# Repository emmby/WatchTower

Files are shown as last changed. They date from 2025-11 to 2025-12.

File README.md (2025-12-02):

# The Watch Tower WWVB transmitter



There are some beautiful radio-controlled watches available these days from Citizen, Seiko, Junghans, and even Casio. These timepieces don’t need fiddling every other month, which is great if you have more than one or two and can never remember what comes after “thirty days hath September…”

In the US, these watches work by receiving a 60-bit 1-Hz signal on a 60-kHz carrier wave broadcast from Fort Collins, Colorado called [WWVB](https://en.wikipedia.org/wiki/WWVB). The broadcast is quite strong and generally covers the entire continental US, but some areas of the country can have unreliable reception. I live in the SF Bay Area in an area with high RF noise and my reception can be spotty. My watches sync often enough that it’s not an issue 363 days out of the year, but sometimes they can miss DST shifts for a day or two. The east coast is known to be even more challenging. And people who live in other countries such as Australia have generally been out of luck.

Wouldn’t it be great if anyone anywhere in the world could set up a home transmitter to broadcast the time so their watches were always in sync?

WWVB has been around awhile and there have been various other projects ([1](https://www.instructables.com/WWVB-radio-time-signal-generator-for-ATTINY45-or-A/),[2](https://github.com/anishathalye/micro-wwvb)) that have demonstrated the feasibility of making your own WWVB transmitter. But these all had very limited range. I wanted to build something that could cover my whole watch stand and be based on a more familiar toolset for the typical hobbyist, namely USB-based 32-bit microcontroller development boards, WiFi, and Arduino. My goal was to make something approachable, reliable, and attractive enough it could sit with my watch collection.

## Is this legal?

The FCC requires a license to transmit, but has an [exemption](https://www.law.cornell.edu/cfr/text/47/15.209) for 60 kHz transmitters as long as the field strength is under 40 *μ*V/m at 300 meters. You will [definitely not](https://github.com/emmby/WatchTower/issues/9) exceed this limit 💪🏼

## About WWVB

The classic WWVB transmits one bit of information per second (1Hz) and takes one minute (60 bits) to transmit a full time and date frame.

### An example

Here’s an example of one 60 second time encoding (graphic designed for "light mode"):



You can see that the minute of the time is encoded in the first 10 seconds of the window. The hour is in the next 10 seconds, the day is between seconds 22 and 33, etc.

If we wanted to indicate that the time was 30 minutes past the hour, for example, we would set bits 2 and 3 (20 and 10) to “high”. 

| **Bit** | **00** | **01** | **02** | **03** | **04** | **05** | **06** | **07** | **08** | **09** |
| --- | --- | --- | --- | --- | --- | --- | --- | --- | --- | --- |
| **Value** |  | 40 | 20 | 10 |  | 8 | 4 | 2 | 1 |  |
| *Example: 30* |  | *0* | *1* | *1* |  | *0* | *0* | *0* | *0* |  |

Similarly, the 7th hour of the day would be 0000111 for bits 12 thru 18.

### It’s a trit, not a bit.

How do we represent “high” and “low” for each 1s bit? You might think it would just be a high voltage for high and a low voltage for low, like you would use on a digital arduino pin, but that’s not how it’s done.

WWVB “bits” are actually not just 0 and 1. They’re actually "trits” because they can represent a 0, 1, or a “mark”, and this is one reason why we can’t just use a simple high/low to represent them. The mark is important to allow simple receivers to orient themselves within the signal window. Your watch knows that the last second in the window and the first in the next window are both “marks”, and so it knows to start a new window whenever it sees two marks in a row.

WWVB uses **Pulse Width Modulation** (PWM) to represent the three possible trit states. In a given 1 second bit, the width of the pulse determines whether the bit is a 0, 1, or mark.

- If power is reduced for one-fifth of a second (0.2 s), this is a data bit with value zero.
- If power is reduced for one-half of a second (0.5 s), this is a data bit with value one.
- If power is reduced for four-fifths of a second (0.8 s), this is a special non-data "mark", used for framing.

| **Low** | **Trit value** |
| --- | --- |
| 0.2s | 0 |
| 0.5s | 1 |
| 0.8s | mark |

Coming back to that original example but just focusing on the Minutes section, you can see the trits in the color encoding of the diagram. 



#07FEFF `Light blue` is high and #0001FC `Dark blue` is low. You can see second 00 is dark blue (low) for 0.8s, which means it’s a “mark”.  Second 01 is dark blue for 0.2s, so it’s a 0. Second 02 is dark blue for 0.5s so it’s a 1, and so on.

So now you know how to encode the time and date using WWVB!

### The carrier wave

There’s one more part of the signal that needs explanation. While we’re transmitting bits at a frequency of 1 bit per second (1 Hz), we’re actually doing it on top of a 60 kHz carrier wave by varying the amplitude of the carrier wave.

Like we said in the previous section, we represent a high/low/mark trit by the width of our pulse. High for 200ms is a zero, high for 500ms is a 1, high for 800ms is a mark. The way we’ll do that on our 60 kHz carrier wave is by using PWM again, but this time on the 60 kHz signal instead of on the 1 Hz signal. We’ll use a duty cycle of 50% to represent High, which means that half of our 60 kHz pulse is high and half is low. We’ll use a duty cycle of 0% to represent Low which effectively means the whole pulse is low.
 
 

 So what you'll expect to see when you're transmitting a WWVB "mark" is a 1s pulse where half of the pulse is "high" using a 60 kHz signal at 50% duty, and the other half is "low" with a 0% duty (not to scale):

 mark

 Similarly, a 0 would be a 60 kHz 50% duty cycle for 0.2s, followed by a 0% duty cycle for 0.8s. And a 1 would be the reverse.

### The layers of WWVB

In summary, a WWVB date/time is encoded using a few different layers of encoding. At the top is what we think of as a date/time and at the bottom is the 60 kHz carrier wave.

|  |
| --- |
| A date/time is encoded as a… |
| 60-bit frame, using… |
| 1s PWM trits, on top of a… |
| 60 kHz 50% duty cycle carrier wave |
| 🐢🐢🐢 all the way down |

Now that you understand how it works, let’s build the transmitter!

## Components

- An ESP32-based development board such as the AdaFruit QT Py ESP32, AdaFruit Feather ESP32 v2, Arduino Nano ESP32, Seeed Xiao ESP32C3 or similar. I used the [QT Py ESP32](https://www.adafruit.com/product/5395).
- An H-bridge amplifier circuit. You can build your own, or I used the [Adafruit DRV8833 DC/Stepper Motor Driver Breakout Board](https://www.adafruit.com/product/3297). Boards using the TB6612 would probably also work, you just need something that can handle 5V or more, a few hundred milliamps and a switching frequency of 60khz or higher.
- One or two [60khz ferrite rod antennas](https://www.canaduino.ca/product/60khz-atomic-clock-receiver-v4-wwvb-msf-jjy60/). You can pull one from an existing quartz radio-controlled movement, or I bought mine from Canaduino. If you want better reliability at distance you may consider using a second antenna. Some users have had luck with a simple 20 inch length of straight copper wire, but I found the signal to be too weak to be reliable.
- Bread board and [jumper wires](https://www.amazon.com/dp/B08YRGVYPV).
- PCB Mount Screw Terminal Block connector to connect your antenna(s), something like [this](https://www.amazon.com/dp/B09F6TC7RP). Not strictly necessary but nice to have. Use a two pin terminal if you only plan to have one antenna, or a four pin if you want two antennas.

## Optional

None of the following is necessary, but some of it might be nice to have.

- **Oscilloscope**. It can be hard to know if your circuit is doing anything without an oscilloscope. There are some micro DSOs for around $100, and some android-based table DSOs for around $200, but I like the Rigol DHO800 series as an entry-level oscilloscope if your budget can stretch to around $400. A digital multimeter or an individual LED can also be helpful in a pinch.
- **10V power supply**. If you need more power you can use an external power supply. I found the signal to be strong enough without it and preferred the convenience of a single USB power supply. If you want to go up to 13V, switch to the [TB6612](https://www.adafruit.com/product/2448)
- **3D printer** if you would like to print the tower enclosure for your circuit.
- **Permaboard** or **Perma-proto**. After you’ve prototyped your circuit you’ll want to move it to something more permanent. [Perma-proto](https://www.adafruit.com/product/571) is convenient because it exactly matches your breadboard layout. Permaboard is more configurable but less convenient. Either one can be cut to size.
- **Soldering iron**. If you’re using permaboard, you’ll need a soldering iron. I love the [Pinecil v2](https://pine64.com/product/pinecil-smart-mini-portable-soldering-iron/), it’s USB-powered, auto-sleep, nearly instant-on, open-source and temperature controlled.
- **GPS module**. The nice thing about using module development boards like the Feather, Grove, Arduino, etc. is their support for additional modules. The [AdaFruit Ultimate GPS FeatherWing](https://www.adafruit.com/product/3133) pairs well with their Feather boards and includes an accurate RTC. If you go GPS, you don’t necessarily need a microcontroller with WiFi.
- **LCD display**. This can be a nice touch and can make it easier to tell if your tower is working or not. I like the [Adafruit ESP32 TFT Feather](https://www.adafruit.com/product/5483) or similar. I made an earlier prototype with a screen that displayed the current time, but didn’t like the way the screen lit up my bedroom at night. You can also connect many external displays using the simple I2C connector on many dev boards.

## Instructions

### Simulator

Before you get started, you might be interested to see a simplified version of the software in action on the Wokwi Arduino online simulator.

The Watch Tower on Wokwi (https://wokwi.com/projects/431240334467357697)
https://wokwi.com/projects/431240334467357697

This simulator connects a virtual Arduino to a virtual logic analyser on PIN 4, and lets you download the output
of PIN 4 for offline viewing on your computer.

To use it:

- Run the simulator for a few seconds. Notice that D0 is
  flashing on the logic analyzer. The logs will also show
  the current date/time (which starts at Jan 1 1970 since
  we aren't using wifi to initialize it to another value)
- Stop the simulator. The logic analyzer will automatically
  download `wokwi-logic.vcd` to your computer.
- Open `wokwi-logic.vcd` in a viewer like [PulseView](https://sigrok.org/wiki/PulseView)

### Software

https://github.com/emmby/WatchTower

Upload the Arduino sketch to your Arduino using the Arduino IDE.

The LED will light up yellow/orange while connecting to WiFi. If you haven’t yet set your SSID, connect your phone to SSID: WWVB and follow the instructions to enter your wifi password.

Once the network is connected and the time has sync’d, the light will turn green briefly and then turn off.

**Setup()**

The Arduino setup() method does a few things.

Initialize the components we’ll be using, particularly the serial port, LEDs, WiFi, output pins, timezone, and network time sync (NTP). The network time sync will happen automatically in the background every hour. This is important because the realtime clock (RTC) on most microcontrollers are notoriously subject to drift and are rarely accurate for more than a few hours.

Start the 60 kHz carrier wave at a 50% duty cycle.

**Loop()**

Arduino then moves to the loop(), which continuously performs the following operations:

- Get the current time in UTC
- Convert it to your local timezone to determine DST
- Compute whether the 60 kHz carrier wave should be set to 50% (logical high) or 0% (logical low) for that specific moment in time. Time is always UTC, except for the DST bit which is relative to your local timezone.
- Set the PIN_ANTENNA to high or low based on that value.
- [Optional] you can flash the led for high/low PWM. This is nice for making sure things are working, but it’s grounds for divorce in the bedroom.

Do some other nice-to-haves like logging, setting LEDs and/or rebooting when there are issues.

### Verify the microcontroller alone

If you installed and ran your software and you set up the wifi connection, your board should now be outputting a signal on your output pin.

If you have an LED, you can connect the long end (anode) to your output pin and the other end to ground. If everything is working it should flash on/off about once a second.



If you have a digital oscilloscope, you should be able to see a 3V square wave with a periodicity of 16us (1 / 60,000) something like the following:



That’s the 50% duty cycle PWM carrier wave initialized during setup().

If you zoom out to say 1 second per grid square resolution, you’ll be able to see the WWVB signal clearly:



In the 10 seconds shown here, I see a 1, mark, 0, 1, 1, mark, 1, 1, 1, and 1.

Now if you modify the software to hardcode the date to Mar 6, 2008 7:30:00 am and zoom out to see a full 60 seconds, your signal should exactly match the signal in the example we started with:

```c
  buf_now_utc.tm_year = buf_now_local.tm_year = 108; // 2008 = 1900 + 108
  buf_now_utc.tm_yday = buf_now_local.tm_yday = 65;
  buf_now_utc.tm_mon = buf_now_local.tm_mon = 2;
  buf_now_utc.tm_mday = buf_now_local.tm_mday = 6;
  buf_now_utc.tm_hour = buf_now_local.tm_hour = 7;
  buf_now_utc.tm_min = buf_now_local.tm_min = 30;
```





Looks great! Everything is working as expected.

### Electronics assembly

Now that you’ve verified the microcontroller is working, it’s time to put all the components together.

The electronics consist of three basic components: the microcontroller board, the amplifier breakout board, and the antenna(s).

The connections are quite simple, you can do them on a breadboard or a proto board. I recommend starting with a breadboard, which will look identical to this perma-proto board but without the solder:



**Microcontroller board** (Adafruit ESP32 QT Py in this photo)

- Connect the 5V pin to the power plane (photo: J1).
- Connect the ground pin to the ground plane (photo: J2).
- Connect your signal pin [M0] to the input pin of your amplifier [AIN1] (photo: J4>J15).

**DRV8833 Amplifier breakout**

I decided to leave a gap between my microcontroller board and my amplifier board. This will support an optional second antenna mounted vertically, and it also makes it easier to access the STEMMA QT I2c connector on the QT Py.

- Connect the second input pin [AIN2] of your amplifier to ground (photo: J16).
- The Adafruit DRV8833 motor driver board has a sleep pin that needs to be pulled high to enable the breakout, so connect that to power 5v or 3v power, whatever is convenient. We used 5V here. (photo: J17)
- Connect ground to the ground plane. (photo: J21)
- [Optional] Connect the “motor” voltage [VM] to your 5V plane (photo: J22). This is needed if you are powering your amplifier via USB like I have here, but it should not be done if you are planning to use an external power supply on VMotor.
The antenna and amplifier circuit can contribute some noise to your 5V line. If you’re worried about it you might use an external power supply instead, but I found for these settings that the noise was negligible (although see Alternatives Considered for some lessons learned).
- Optional: connect BIN2 to ground (photo: J18). This is only needed if you want to use a second antenna.
- Optional: connect BIN1 to AIN1 (**not in photo**: I15>I19). For a second antenna.

**Antenna(s)**

- You can plug your antennas directly into your breadboard, or use a 0.1" Pitch PCB Mount Screw Terminal Block Connector connected to [AOUT1], [AOUT2], [BOUT2], and [BOUT1] (photo: C16, C17, C18, C19). If you are only using one antenna, you only need [AOUT1] and [AOUT2].

  The orientation of the antenna has a profound effect on the strength of the signal. I recommend using a second antenna at a 90 degree orientation to the first. You won't get a more powerful signal, but by having a second signal at a 90 degree orientiation you significanly increase the chance that your watches will be able to pick up a signal (see the section on antenna orientation below). The amplifier can easily handle two antennas.

  With one antenna, I was getting around 12 inches of range with the way my watches were oriented. With the second antenna, that jumped up to more than 6 feet!

  The STL tower has a hole in the center to allow space for a 60mm ferrite rod antenna mounted vertically in the gap between the microcontroller and amplifier PCBs.

### Signal Verification

You should be able to do the same LED trick as last time, only this time with the long anode on AOUT1 and the short cathode on AOUT2.

Or with your oscilloscope, you can look at the output of your microcontroller and compare it to the output of your amplifier:



Here the 3V signal on the microcontroller is blue, and you can see that the amplifier is outputting a similar wave but at 5V. If your wave doesn’t look quite like this, check that your antenna is plugged in. The antenna has an impedance that will cause the ringing that you see in the waveform, that’s expected and okay.

The final test is to verify it works with a real watch!



### Assembling the enclosure

The enclosure is designed for a 51mm x 63mm perma-proto, which is the size of a half size perma-proto with the excess trimmed. You can trim a proto board by scoring along a straightedge with a utility knife and then bending the board at the score, either by pressing it down on a hard surface at an angle or using a vise grip. Or feel free to modify the Autodesk Fusion file to the size of your own board.



Here I also made a quick and dirty “mount” for the antenna by twisting a couple of loops of wire and soldering them to the perma proto. Hot glue also works great.

Print the enclosure using a 3D printer. I used standard PLA, standard 0.4mm nozzle, and pretty much default slicer settings with no supports.

* STL: [The Watch Tower.stl](enclosure/The%20Watch%20Tower%20v18.stl)
* Autodesk Fusion: [The Watch Tower.f3d](enclosure/The%20Watch%20Tower%20v18.f3d)



Insert the circuit board into the base. Orient the second antenna between the two PCBs and fit it into the hole in the tower. Then press the lid for a snap fit.

## Enjoy!

Plug into USB and you’re done! Your watches should now sync automatically every night.



## Signal strength

### How does distance affect signal strength?

You probably expect the signal to decrease as you get further away from the tower, but you might be surprised by how quickly the signal disappears.

The "inverse square law" tells us that RF signal strength decreases with the square of the distance. We can measure our signal strength using our oscilloscope, another antenna, and a ruler.

signal strength at 1 inch setup

At one inch, our signal strength looks pretty solid! You can see that our 5V antenna square wave (yellow) is inducing a 16V sinusoidal wave in our receiving antenna. It's a little counter-intuitive that the receiving amplitude would be larger than the sending amplitude, but RF physics is beyond the scope of this README. Which is another way of saying 🤷.

signal strength at 1 inch

Here are my readings as I move the receiver antenna further out. As expected, the amplitude decreases by roughly 4X as the distance doubles. 

| Distance | Amplitude |
|----|---|
| 1" | 24.2V |
| 2" | 6.7V |
| 4" | 1.2V |
| 8" | 301mV |
| 16" | 93mV |
| 32" | 28mV |

When you zoom out, the one second pulses are still clearly distinguishable to the human eye, but it gets harder and harder as you get further away.



This is all fine and good, but seeing a wave on an oscilloscope doesn't necessarily mean the watch can pick it up. We'll get into that shortly.

### How does orientation affect signal strength?

Quite a lot!

Turning the receiver antenna 90 degrees drops the signal by 75%!

rotation

Most watches receive their strongest signal through the watch face. For the best reception you should point your watch toward the tower (or toward Colorado). This may make more of a difference than a few inches of distance.

This doesn't matter for watches on the stand where the signal is strong, but it can make a difference for watches that are further away.

This is why I recommend two antennas at right angles from each other.

### Does the enclosure affect signal strength?

Plastic enclosures have a negligible effect on signal strength. The Watch Tower enclosure printed using generic PLA has maybe 5% or less of an impact on signal strength. Again, a few degrees of orientation will have a larger effect than an enclosure.

|||
|-|-|
|No enclosure | 1.02V |
|Base | 952mV |
|Fully enclosed | 987mV |

### How far away can my watch pick up the signal?

Watches vary in terms of their antenna design, their enclosures, antenna orientation, signal-to-noise filtering, etc.

I tested with a Junghans Max Bill Mega Solar 59/2021.02 (Seiko movement) and a Casio Lineage LIW-M700D (Casio movement). In practice, the orientation of your watch will probably have orders of magnitude more influence on your reception than the model of your watch.

Using the SINGLE antenna, I made five attempts with each watch at a distance of 9" with the antenna and the watch both flat on the surface. To minimize interference from Fort Collins, I placed everything inside a poor man's faraday cage (a stainless steel stock pot with a tight lid, which Gemini tells me is reasonably effective at blocking 60 kHz signals). For each attempt, I gave the watch 5 minutes to try to set the time before I lifted the lid. 

clock in a pot

| Model ||||||
|---|-----|-|-|-|-|
| Casio | Yes | No | Yes | Yes | Yes |
| Junghans| Yes | Yes | Yes | Yes | Yes |

Outcome: ~90% success at 9" (single antenna)

In practice, I've found that watches on the Watch Tower will reliably sync every time, and most watches on my nearby watch stand will also sync most of the time using a single antenna. Adding the second antenna increases reliability to basically 100%.

## Alternatives considered

- I wanted to avoid using a separate amplifier breakout board so I tried the Adafruit RP2040 scorpio. It can do 60khz PWM at 5V natively, but it was only able to drive 12mA per channel which wasn’t enough to saturate my ferrite antenna so the square wave collapsed.
- I looked at the **Adafruit 8-Channel PWM or Servo FeatherWing** because I wanted to take advantage of module stacking, but it can only do 10mA per channel and 1.6khz.
- I looked at Trinket and Itsybitsy ATmega based boards, but they can’t drive much current and they’re not modular with anything and they have no wifi so there’s little advantage over the QT Py.
- I considered driving the DRV8833 with an external power supply. This would have given me higher voltage and likely a stronger signal. But I wanted the convenience of a single usb power supply, and the signal strength was sufficient for my needs.
- ⚠️ **WARNING**: I tried the linking both the A and B H-bridges of the  DRV8833 in parallel, and I also upped the duty cycle to 80%. Totally blew out my microcontroller, presumably with a flyback voltage due to the high inductance antenna. I’m not sure if it was the parallel or the 80% or the combination of the two, it would be worth experimenting further but I haven’t yet.

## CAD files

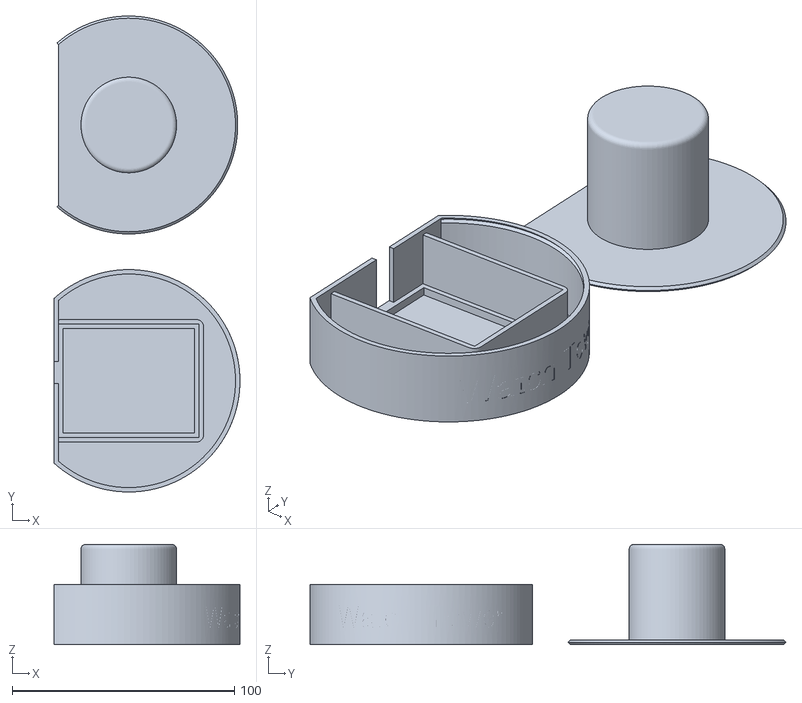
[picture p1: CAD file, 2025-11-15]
enclosure/The Watch Tower.stl
83.6 x 214.0 x 45.0

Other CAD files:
enclosure/The Watch Tower.f3d

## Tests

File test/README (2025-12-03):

This directory is intended for PlatformIO Test Runner and project tests.

Unit Testing is a software testing method by which individual units of
source code, sets of one or more MCU program modules together with associated
control data, usage procedures, and operating procedures, are tested to
determine whether they are fit for use. Unit testing finds problems early
in the development cycle.

More information about PlatformIO Unit Testing:
- https://docs.platformio.org/en/latest/advanced/unit-testing/index.html

These test can be run using the PlatformIO Test Runner.
    cmd+shift+p PlatformIO: Test in VS Code
or
    pio test -e native

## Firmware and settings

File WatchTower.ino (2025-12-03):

// INSTRUCTIONS
// - Add the following dependencies to your Arduino libraries:
//     - Adafruit NeoPixel ~1.15.2
//     - ESPUI ~2.2.4
//     - ESP32Async / ESP Async WebServer ~3.9.0
//     - ESP32Async / Async TCP ~3.4.9
//     - WiFiManager ~2.0.17
//     - ArduinoMDNS ~1.0.0
// - set the PIN_ANTENNA to desired output pin
// - set the timezone as desired
// - build and run the code on your device
// - connect your phone to "WatchTower" to set the wifi config for the device
// - connect to http://watchtower.local to view current status

// Designed for the following, but should be easily
// transferable to other components:
// - Adafruit Qt Py ESP32 Pico: https://www.adafruit.com/product/5395
// - Adafruit DRV8833 breakout: https://www.adafruit.com/product/3297
// Also tested on
// - Adafruit ESP32 Feather v2
// - Arduino Nano ESP32 (via wokwi)

#include <WiFiManager.h>
#include <Adafruit_NeoPixel.h>
#include <SPI.h>
#include <ESPUI.h>
#include <WiFiUdp.h>
#include <ArduinoMDNS.h>
#include <time.h>
#include <esp_sntp.h>
#include "customJS.h"

// Flip to false to disable the built-in web ui.
// You might want to do this to avoid leaving unnecessary open ports on your network.
const bool ENABLE_WEB_UI = true;

// Set this to the pin your antenna is connected on
const int PIN_ANTENNA = 13;

// Set to your timezone.
// This is needed for computing DST if applicable
// https://gist.github.com/alwynallan/24d96091655391107939
const char *timezone = "PST8PDT,M3.2.0,M11.1.0"; // America/Los_Angeles


enum WWVB_T {
  ZERO = 0,
  ONE = 1,
  MARK = 2,
};

const int KHZ_60 = 60000;
const char* const ntpServer = "pool.ntp.org";

// Configure the optional onboard neopixel
#ifdef PIN_NEOPIXEL
Adafruit_NeoPixel* const pixel = new Adafruit_NeoPixel(1, PIN_NEOPIXEL, NEO_GRB + NEO_KHZ800);
#else
Adafruit_NeoPixel* const pixel = NULL;
#endif

const uint8_t LED_BRIGHTNESS = 10; // very dim, 0-255
const uint32_t COLOR_READY = pixel ? pixel->Color(0, 60, 0) : 0; // green https://share.google/4WKm4XDkH9tfm3ESC
const uint32_t COLOR_LOADING = pixel ? pixel->Color(60, 32, 0) : 0; // orange https://share.google/7tT5GPxskZi8t8qmx
const uint32_t COLOR_ERROR = pixel ? pixel->Color(150, 0, 0) : 0; // red https://share.google/nx2jWYSoGtl0opkzL
const uint32_t COLOR_TRANSMIT = pixel ? pixel->Color(32, 0, 0) : 0; // dim red https://share.google/wYFYM3t1kDeOJfr1U

WiFiManager wifiManager;
WiFiUDP udp;
MDNS mdns(udp);
bool logicValue = 0; // TODO rename
struct timeval lastSync;
WWVB_T broadcast[60];

// ESPUI Interface IDs
uint16_t ui_time;
uint16_t ui_date;
uint16_t ui_timezone;
uint16_t ui_broadcast;
uint16_t ui_uptime;
uint16_t ui_last_sync;

// A callback that tracks when we last sync'ed the
// time with the ntp server
void time_sync_notification_cb(struct timeval *tv) {
  lastSync = *tv;
}

// A callback that is called when the device
// starts up an access point for wifi configuration.
// This is called when the device cannot connect to wifi.
void accesspointCallback(WiFiManager*) {
  Serial.println("Connect to SSID: WatchTower with another device to set wifi configuration.");
}

// Convert a logical bit into a PWM pulse width.
// Returns 50% duty cycle (128) for high, 0% for low
static inline short dutyCycle(bool logicValue) {
  return logicValue ? (256*0.5) : 0; // 128 == 50% duty cycle
}

static inline int is_leap_year(int year) {
    return (year % 4 == 0) && (year % 100 != 0 || year % 400 == 0);
}

void clearBroadcastValues() {
    for(int i=0; i<sizeof(broadcast)/sizeof(broadcast[0]); ++i) {
        broadcast[i] = (WWVB_T)-1; // -1 isn't legal but that's okay, we just need an invalid value
    }
}

void setup() {
  Serial.begin(115200);
  delay(1000);

  pinMode(PIN_ANTENNA, OUTPUT);
  if( pixel ) {
    pixel->begin();
    pixel->setBrightness(LED_BRIGHTNESS); // very dim
    pixel->setPixelColor(0, COLOR_LOADING );
    pixel->show();
  }

  // E (14621) rmt: rmt_new_tx_channel(269): not able to power down in light sleep
  digitalWrite(PIN_ANTENNA, 0);

  // https://github.com/tzapu/WiFiManager/issues/1426
  WiFi.setScanMethod(WIFI_ALL_CHANNEL_SCAN);

  // Connect to WiFi using // https://github.com/tzapu/WiFiManager 
  // If no wifi, start up an SSID called "WatchTower" so
  // the user can configure wifi using their phone.
  wifiManager.setAPCallback(accesspointCallback);
  wifiManager.autoConnect("WatchTower");

  clearBroadcastValues();

  // --- ESPUI SETUP ---
  ESPUI.setVerbosity(Verbosity::Quiet);
  
  // Create Labels
  ui_broadcast = ESPUI.label("Broadcast Waveform", ControlColor::Sunflower, "");
  ui_time = ESPUI.label("Current Time", ControlColor::Turquoise, "Loading...");
  ui_date = ESPUI.label("Date", ControlColor::Emerald, "Loading...");
  ui_timezone = ESPUI.label("Timezone", ControlColor::Peterriver, timezone);
  ui_uptime = ESPUI.label("System Uptime", ControlColor::Carrot, "0s");
  ui_last_sync = ESPUI.label("Last NTP Sync", ControlColor::Alizarin, "Pending...");

  ESPUI.setPanelWide(ui_broadcast, true);
  ESPUI.setElementStyle(ui_broadcast, "font-family: monospace");
  ESPUI.setCustomJS(customJS);

  // You may disable the internal webserver by commenting out this line
  if( ENABLE_WEB_UI ) {
    mdns.begin(WiFi.localIP(), "watchtower");
    Serial.println("Connect to http://watchtower.local for the console");
    ESPUI.begin("WatchTower");
  }
  
  // --- TIME SYNC ---

  // Connect to network time server
  // By default, it will resync every few hours
  sntp_set_time_sync_notification_cb(time_sync_notification_cb);
  configTzTime(timezone, ntpServer);
  
  struct tm timeinfo;
  if(!getLocalTime(&timeinfo)){
    Serial.println("Failed to obtain time");
    if( pixel ) {
        pixel->setPixelColor(0, COLOR_ERROR );
        pixel->show();
    }
    delay(3000);
    ESP.restart();
  }
  Serial.println("Got the time from NTP");

  // Start the 60khz carrier signal using 8-bit (0-255) resolution
  ledcAttach(PIN_ANTENNA, KHZ_60, 8);

  // green means go
  if( pixel ) {
    pixel->setPixelColor(0, COLOR_READY );
    pixel->show();
    delay(3000);
    pixel->clear();  
    pixel->show();
  }
}

void loop() {
  mdns.run();

  struct timeval now; // current time in seconds / millis
  struct tm buf_now_utc; // current time in UTC
  struct tm buf_now_local; // current time in localtime
  struct tm buf_today_start, buf_tomorrow_start; // start of today and tomrrow in localtime
  static int prev_second_display = -1; // for tracking UI updates

  gettimeofday(&now,NULL);
  localtime_r(&now.tv_sec, &buf_now_local);
  gmtime_r(&now.tv_sec, &buf_now_utc); 

  // compute start of today for dst
  struct timeval today_start = now;
  today_start.tv_usec = 0;
  today_start.tv_sec = (today_start.tv_sec / 86400) * 86400; // This is not exact but close enough
  localtime_r(&today_start.tv_sec, &buf_today_start);

  // compute start of tomorrow for dst
  struct timeval tomorrow_start = now;
  tomorrow_start.tv_usec = 0;
  tomorrow_start.tv_sec = ((tomorrow_start.tv_sec / 86400) + 1) * 86400; // again, close enough
  localtime_r(&tomorrow_start.tv_sec, &buf_tomorrow_start);

  const bool prevLogicValue = logicValue;

  logicValue = wwvbLogicSignal(
    buf_now_utc.tm_hour,
    buf_now_utc.tm_min,
    buf_now_utc.tm_sec, 
    now.tv_usec/1000,
    buf_now_utc.tm_yday+1,
    buf_now_utc.tm_year+1900,
    buf_today_start.tm_isdst,
    buf_tomorrow_start.tm_isdst
    );

  // --- UI UPDATE LOGIC ---
  if( logicValue != prevLogicValue ) {
    ledcWrite(PIN_ANTENNA, dutyCycle(logicValue));  // Update the duty cycle of the PWM

    // light up the pixel if desired
    if( pixel ) {
      if( logicValue == 1 ) {
        pixel->setPixelColor(0, COLOR_TRANSMIT ); // don't call show yet, the color may change
      } else {
        pixel->clear();
      }
    }

    // do any logging after we set the bit to not slow anything down,
    // serial port I/O is slow!
    char timeStringBuff[100]; // Buffer to hold the formatted time string
    char timeStringBuff2[100];
    char timeStringBuff3[20];
    strftime(timeStringBuff, sizeof(timeStringBuff), "%A, %B %d %Y %H:%M:%S", &buf_now_local); // time
    strftime(timeStringBuff3, sizeof(timeStringBuff3), "%z %Z", &buf_now_local); // timezone
    sprintf(timeStringBuff2,"%s.%03d%s", timeStringBuff, now.tv_usec/1000, timeStringBuff3 ); // time+millis+tz

    char lastSyncStringBuff[100]; // Buffer to hold the formatted time string
    struct tm buf_lastSync;
    localtime_r(&lastSync.tv_sec, &buf_lastSync);
    strftime(lastSyncStringBuff, sizeof(lastSyncStringBuff), "%b %d %H:%M", &buf_lastSync);
    Serial.printf("%s [last sync %s]: %s\n",timeStringBuff2, lastSyncStringBuff, logicValue ? "1" : "0");

    static int prevSecond = -1;
    if( prevSecond != buf_now_utc.tm_sec ) {
        prevSecond = buf_now_utc.tm_sec;

        // --- UPDATE THE WEB UI ---

        // Time
        char buf[62];
        strftime(buf, sizeof(buf), "%H:%M:%S%z %Z", &buf_now_local);
        ESPUI.print(ui_time, buf);

        // Date
        strftime(buf, sizeof(buf), "%A, %B %d %Y", &buf_now_local);
        ESPUI.print(ui_date, buf);

        // Broadcast window
        for( int i=0; i<60; ++i ) { // TODO leap seconds
        switch(broadcast[i]) {
            case WWVB_T::MARK:
                buf[i] = 'M';
                break;
            case WWVB_T::ZERO:
                buf[i] = '0';
                break;
            case WWVB_T::ONE:
                buf[i] = '1';
                break;
            default:
                buf[i] = ' ';
                break;
        }
        }
        ESPUI.print(ui_broadcast, buf);


        // Uptime
        long uptime = millis() / 1000;
        int up_d = uptime / 86400;
        int up_h = (uptime % 86400) / 3600;
        int up_m = (uptime % 3600) / 60;
        int up_s = uptime % 60;
        snprintf(buf, sizeof(buf), "%03dd %02dh %02dm %02ds", up_d, up_h, up_m, up_s);
        ESPUI.print(ui_uptime, buf);

        // Last Sync
        strftime(buf, sizeof(buf), "%b %d %H:%M", &buf_lastSync);
        ESPUI.print(ui_last_sync, buf);
    }

    // Check for stale sync (24 hours)
    if( now.tv_sec - lastSync.tv_sec > 60 * 60 * 24 ) {
      Serial.println("Last sync more than 24 hours ago, rebooting.");
      if( pixel ) {
        pixel->setPixelColor(0, COLOR_ERROR );
        delay(3000);
      }
      ESP.restart();
    }

    if( pixel ) {
        pixel->show();
    }
  }  
}


// Returns a logical high or low to indicate whether the
// PWM signal should be high or low based on the current time
// https://www.nist.gov/pml/time-and-frequency-division/time-distribution/radio-station-wwvb/wwvb-time-code-format
bool wwvbLogicSignal(
    int hour,                // 0 - 23
    int minute,              // 0 - 59
    int second,              // 0 - 59 (leap 60)
    int millis,
    int yday,                // days since January 1 eg. Jan 1 is 0
    int year,                // year since 0, eg. 2025
    int today_start_isdst,   // was this morning DST?
    int tomorrow_start_isdst // is tomorrow morning DST?
) {
    int leap = is_leap_year(year);
    
    WWVB_T bit;
    switch (second) {
        case 0: // mark
            bit = WWVB_T::MARK;
            break;
        case 1: // minute 40
            bit = (WWVB_T)(((minute / 10) >> 2) & 1);
            break;
        case 2: // minute 20
            bit = (WWVB_T)(((minute / 10) >> 1) & 1);
            break;
        case 3: // minute 10
            bit = (WWVB_T)(((minute / 10) >> 0) & 1);
            break;
        case 4: // blank
            bit = WWVB_T::ZERO;
            break;
        case 5: // minute 8
            bit = (WWVB_T)(((minute % 10) >> 3) & 1);
            break;
        case 6: // minute 4
            bit = (WWVB_T)(((minute % 10) >> 2) & 1);
            break;
        case 7: // minute 2
            bit = (WWVB_T)(((minute % 10) >> 1) & 1);
            break;
        case 8: // minute 1
            bit = (WWVB_T)(((minute % 10) >> 0) & 1);
            break;
        case 9: // mark
            bit = WWVB_T::MARK;
            break;
        case 10: // blank
            bit = WWVB_T::ZERO;
            break;
        case 11: // blank
            bit = WWVB_T::ZERO;
            break;
        case 12: // hour 20
            bit = (WWVB_T)(((hour / 10) >> 1) & 1);
            break;
        case 13: // hour 10
            bit = (WWVB_T)(((hour / 10) >> 0) & 1);
            break;
        case 14: // blank
            bit = WWVB_T::ZERO;
            break;
        case 15: // hour 8
            bit = (WWVB_T)(((hour % 10) >> 3) & 1);
            break;
        case 16: // hour 4
            bit = (WWVB_T)(((hour % 10) >> 2) & 1);
            break;
        case 17: // hour 2
            bit = (WWVB_T)(((hour % 10) >> 1) & 1);
            break;
        case 18: // hour 1
            bit = (WWVB_T)(((hour % 10) >> 0) & 1);
            break;
        case 19: // mark
            bit = WWVB_T::MARK;
            break;
        case 20: // blank
            bit = WWVB_T::ZERO;
            break;
        case 21: // blank
            bit = WWVB_T::ZERO;
            break;
        case 22: // yday of year 200
            bit = (WWVB_T)(((yday / 100) >> 1) & 1);
            break;
        case 23: // yday of year 100
            bit = (WWVB_T)(((yday / 100) >> 0) & 1);
            break;
        case 24: // blank
            bit = WWVB_T::ZERO;
            break;
        case 25: // yday of year 80
            bit = (WWVB_T)((((yday / 10) % 10) >> 3) & 1);
            break;
        case 26: // yday of year 40
            bit = (WWVB_T)((((yday / 10) % 10) >> 2) & 1);
            break;
        case 27: // yday of year 20
            bit = (WWVB_T)((((yday / 10) % 10) >> 1) & 1);
            break;
        case 28: // yday of year 10
            bit = (WWVB_T)((((yday / 10) % 10) >> 0) & 1);
            break;
        case 29: // mark
            bit = WWVB_T::MARK;
            break;
        case 30: // yday of year 8
            bit = (WWVB_T)(((yday % 10) >> 3) & 1);
            break;
        case 31: // yday of year 4
            bit = (WWVB_T)(((yday % 10) >> 2) & 1);
            break;
        case 32: // yday of year 2
            bit = (WWVB_T)(((yday % 10) >> 1) & 1);
            break;
        case 33: // yday of year 1
            bit = (WWVB_T)(((yday % 10) >> 0) & 1);
            break;
        case 34: // blank
            bit = WWVB_T::ZERO;
            break;
        case 35: // blank
            bit = WWVB_T::ZERO;
            break;
        case 36: // UTI sign +
            bit = WWVB_T::ONE;
            break;
        case 37: // UTI sign -
            bit = WWVB_T::ZERO;
            break;
        case 38: // UTI sign +
            bit = WWVB_T::ONE;
            break;
        case 39: // mark
            bit = WWVB_T::MARK;
            break;
        case 40: // UTI correction 0.8
            bit = WWVB_T::ZERO;
            break;
        case 41: // UTI correction 0.4
            bit = WWVB_T::ZERO;
            break;
        case 42: // UTI correction 0.2
            bit = WWVB_T::ZERO;
            break;
        case 43: // UTI correction 0.1
            bit = WWVB_T::ZERO;
            break;
        case 44: // blank
            bit = WWVB_T::ZERO;
            break;
        case 45: // year 80
            bit = (WWVB_T)((((year / 10) % 10) >> 3) & 1);
            break;
        case 46: // year 40
            bit = (WWVB_T)((((year / 10) % 10) >> 2) & 1);
            break;
        case 47: // year 20
            bit = (WWVB_T)((((year / 10) % 10) >> 1) & 1);
            break;
        case 48: // year 10
            bit = (WWVB_T)((((year / 10) % 10) >> 0) & 1);
            break;
        case 49: // mark
            bit = WWVB_T::MARK;
            break;
        case 50: // year 8
            bit = (WWVB_T)(((year % 10) >> 3) & 1);
            break;
        case 51: // year 4
            bit = (WWVB_T)(((year % 10) >> 2) & 1);
            break;
        case 52: // year 2
            bit = (WWVB_T)(((year % 10) >> 1) & 1);
            break;
        case 53: // year 1
            bit = (WWVB_T)(((year % 10) >> 0) & 1);
            break;
        case 54: // blank
            bit = WWVB_T::ZERO;
            break;
        case 55: // leap year
            bit = leap ? WWVB_T::ONE : WWVB_T::ZERO;
            break;
        case 56: // leap second
            bit = WWVB_T::ZERO;
            break;
        case 57: // dst bit 1
            bit = today_start_isdst ? WWVB_T::ONE : WWVB_T::ZERO;
            break;
        case 58: // dst bit 2
            bit = tomorrow_start_isdst ? WWVB_T::ONE : WWVB_T::ZERO;
            break;
        case 59: // mark
            bit = WWVB_T::MARK;
            break;
    }

    if(second == 0) {
        clearBroadcastValues();
    }
    broadcast[second] = bit;

    // Convert a wwvb zero, one, or mark to the appropriate pulse width
    // zero: low 200ms, high 800ms
    // one: low 500ms, high 500ms
    // mark low 800ms, high 200ms
    if (bit == WWVB_T::ZERO) {
      return millis >= 200;
    } else if (bit == WWVB_T::ONE) {
      return millis >= 500;
    } else {
      return millis >= 800;
    }
}

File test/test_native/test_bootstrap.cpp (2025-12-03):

#include <Arduino.h>
#include <unity.h>
#include <string>
#include <vector>
#include <sys/time.h>
#include <cstdarg>

// Mocks
#include "WiFiManager.h"
#include "Adafruit_NeoPixel.h"
#include "ESPUI.h"
#include "WiFiUdp.h"
#include "ArduinoMDNS.h"
#include "esp_sntp.h"
#include "WiFi.h"
#include "Esp.h"
#include "SPI.h"

// Globals for mocks
WiFiClass WiFi;
ESPUIClass ESPUI;
EspClass ESP;
SPIClass SPI;

// Core functions
void delay(unsigned long ms) {}
unsigned long millis() { return 0; }
void pinMode(uint8_t pin, uint8_t mode) {}
void digitalWrite(uint8_t pin, uint8_t val) {}

// Mock gettimeofday
struct timeval mock_tv = {0, 0};
int mock_gettimeofday(struct timeval *tv, void *tz) {
    if (tv) *tv = mock_tv;
    return 0;
}
#define gettimeofday mock_gettimeofday

// Mock Serial to support printf
class SerialMock {
public:
    std::string output;
    void begin(unsigned long) {}
    void println(const char* s) { output += s; output += "\n"; }
    void println(String s) {}
    void println(int i) { output += std::to_string(i); output += "\n"; }
    void println() { output += "\n"; }
    void print(const char* s) { output += s; }
    void print(int i) { output += std::to_string(i); }
    void printf(const char * format, ...) {
        char buffer[256];
        va_list args;
        va_start(args, format);
        vsnprintf(buffer, sizeof(buffer), format, args);
        va_end(args);
        output += buffer;
    }
};
SerialMock MySerial;
#define Serial MySerial

// ESP32 specific mocks
void ledcAttach(uint8_t pin, double freq, uint8_t resolution) {}
void ledcWrite(uint8_t pin, uint32_t duty) {}
void configTzTime(const char* tz, const char* server1, const char* server2 = nullptr, const char* server3 = nullptr) {}
bool getLocalTime(struct tm* info, uint32_t ms = 5000) {
    time_t now;
    time(&now);
    localtime_r(&now, info);
    return true;
}
void sntp_set_time_sync_notification_cb(sntp_sync_time_cb_t callback) {}

// Forward declarations for functions in WatchTower.ino that are used before definition
bool wwvbLogicSignal(int, int, int, int, int, int, int, int);

// Rename timezone to avoid conflict with system symbol
#define timezone my_timezone

// Include the sketch
// We need to trick the compiler into treating .ino as .cpp and handling the setup/loop
#include "../../WatchTower.ino"

void setUp(void) {
    MySerial.output = "";
    WiFiManager::calledAutoConnect = false;
    memset(WiFiManager::lastSSID, 0, sizeof(WiFiManager::lastSSID));
    // Set TZ to UTC for predictable testing
    setenv("TZ", "UTC", 1);
    tzset();
}

void tearDown(void) {
}

void test_setup_completes(void) {
    // Arrange
    // (Mocks are already set up to do nothing or return defaults)

    // Act
    setup();

    // Assert
    // Verify that setup completed without crashing
    // We can also verify that specific functions were called if we used strict mocks,
    // but for now we just want to ensure it boots.
    TEST_ASSERT_TRUE(true);
}

void test_wifi_connection_attempt(void) {
    // Arrange
    // Act
    setup();

    // Assert
    TEST_ASSERT_TRUE(WiFiManager::calledAutoConnect);
    TEST_ASSERT_EQUAL_STRING("WatchTower", WiFiManager::lastSSID);
}

void test_serial_date_output(void) {
    // Arrange
    // Set time to 2025-12-25 12:00:00 UTC
    // 1766664000
    mock_tv.tv_sec = 1766664000; 
    mock_tv.tv_usec = 900000; // 900ms to ensure logicValue=1 (MARK/ONE/ZERO all high at 900ms? No wait)
    // ZERO: low 200ms, high 800ms. So at 900ms (0.9s), it is HIGH (Wait, "low 200ms, high 800ms" usually means low FOR 200ms, then high FOR 800ms? Or low UNTIL 200ms?)
    // WatchTower.ino:
    // if (bit == WWVB_T::ZERO) return millis >= 200;
    // So if millis (0-999) >= 200, it returns true (High).
    // So 900 >= 200 is True.
    // So logicValue will be 1.
    // prevLogicValue init is 0.
    // So it should print.
    
    // Act
    setup(); // Initialize
    loop();  // Run loop once

    // Assert
    // Expected output format: "Thursday, December 25 2025 12:00:00.900 +0000 UTC [last sync Pending...]: 1"
    // Note: The exact string depends on strftime implementation and locale, but usually standard C is consistent.
    // Also "Pending..." because lastSync is not set in this test path (unless setup sets it? No, callback does).
    
    // We'll check for the date part to be safe
    TEST_ASSERT_NOT_NULL(strstr(MySerial.output.c_str(), "December 25 2025"));
}

void test_wwvb_logic_signal(void) {
    // Test ZERO bit (e.g. second 4 is always ZERO/Blank)
    // Expect: False for < 200ms, True for >= 200ms
    TEST_ASSERT_FALSE(wwvbLogicSignal(0, 0, 4, 199, 0, 2025, 0, 0));
    TEST_ASSERT_TRUE(wwvbLogicSignal(0, 0, 4, 200, 0, 2025, 0, 0));

    // Test ONE bit (e.g. second 1, minute 40 -> bit 2 is 1)
    // Minute 40 = 101000 binary? No. 40 / 10 = 4. 4 in binary is 100.
    // Second 1 checks bit 2 of (minute/10). (4 >> 2) & 1 = 1. So it's a ONE.
    // Expect: False for < 500ms, True for >= 500ms
    TEST_ASSERT_FALSE(wwvbLogicSignal(0, 40, 1, 499, 0, 2025, 0, 0));
    TEST_ASSERT_TRUE(wwvbLogicSignal(0, 40, 1, 500, 0, 2025, 0, 0));

    // Test MARK bit (e.g. second 0 is always MARK)
    // Expect: False for < 800ms, True for >= 800ms
    TEST_ASSERT_FALSE(wwvbLogicSignal(0, 0, 0, 799, 0, 2025, 0, 0));
    TEST_ASSERT_TRUE(wwvbLogicSignal(0, 0, 0, 800, 0, 2025, 0, 0));
}
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

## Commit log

2025-11-09 Potential fix for daylight savings time issue.
    switched from configTime to configTzTime, which
    in theory should respect DST flag.
    hopefully this might explain why my watches did not
    pick up the right time on Nov 2
    [WatchTower.ino]
2025-11-15 print proper timezone info
2025-11-15 Separate enclosure lid and body to make printing more straightforward.
    https://github.com/emmby/WatchTower/issues/2
    [The Watch Tower v18.f3d, The Watch Tower v18.stl, The Watch Tower.f3d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]
2025-11-16 Switch from I2C screen debugging to webserver
2025-11-16 fix crash in mdns. also add back pixels.show
    [WatchTower.ino]
2025-11-16 replace forcereboot with ESP.restart
    [WatchTower.ino]
2025-11-16 replace pixels. with pixel->
    [WatchTower.ino]
2025-11-21 Make the panel wider and switch to raw strings
2025-11-22 fix alignment of table and canvas
    [WatchTower.ino]
2025-12-03 add test to print current date to serial port
2026-11-09 docs: update README, photos, and 3D model for 1/4-size Perma-Proto and 100uF capacitor
2026-11-12 fix: drive WWVB PWM transitions via 1ms esp_timer and harden Web UI / reboot behavior
2026-11-12 fix: sample time inside transitionOccurred handler and avoid clearing broadcast[0]
